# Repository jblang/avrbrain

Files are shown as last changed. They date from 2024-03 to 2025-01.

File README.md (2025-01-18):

# AVRBrain

AVRbrain is an [AVR128DB64](https://www.microchip.com/en-us/product/avr128db64) dev board.  The AVR Dx series are modern AVRs with many desireable features over the classic ATmega AVRs, such as multi-voltage I/O, configurable logic, advanced analog features, and a single-wire programming and debug interface.

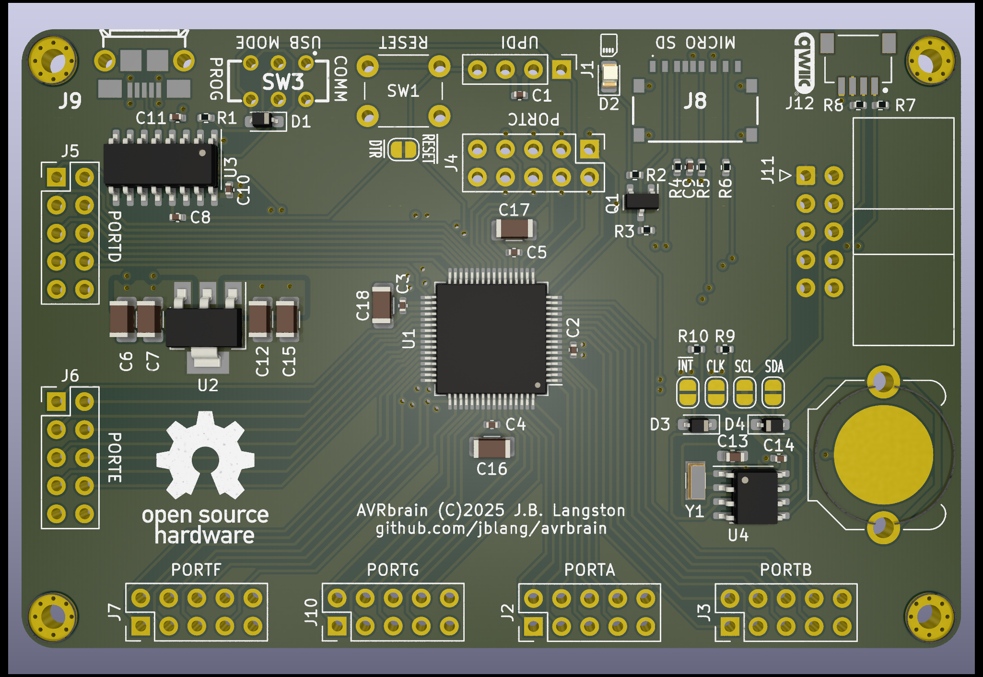
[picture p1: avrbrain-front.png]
3D Render


## Arduino Compatibility

AVRbrain is compatible with the [DxCore](https://github.com/SpenceKonde/DxCore) Arduino Core. I have tested the AVR128DB28 on a breadboard with the same programming circuit I intend to use on the finished board, and confirmed that it works.

Once flashed in UPDI programming mode, the Optiboot_Dx bootloader can be used to reprogram the board in serial comms mode, and there is an auto-reset circuit connected to the DTR line (possible to disable with a jumper).

## PlatformIO Compatibility

AVRbrain is compatible with [PlatformIO](https://platformio.org/) using the [Atmel megaAVR platform](https://docs.platformio.org/en/latest/platforms/atmelmegaavr.html).  PlatformIO supports Arduino development using DxCore, or native development using [avr-libc](https://www.nongnu.org/avr-libc/).  

Here's the `platformio.ini` that I used to build a simple non-Arduino led blinking example for the AVR128DB64:
```
[env:AVR128DB28]
platform = atmelmegaavr
platform_packages = platformio/toolchain-atmelavr@^3.70300.220127
board = AVR128DB28
upload_speed = 115200
upload_flags = 
    --tool
    uart
    --device
    avr128db28
    --uart
    $UPLOAD_PORT
    --clk
    $UPLOAD_SPEED
upload_command = pymcuprog write --erase $UPLOAD_FLAGS --filename $SOURCE
```

The above example can be made to work with DxCore just by adding the line `framework = arduino` to this file.

## Hardware Features
- Onboard CH340C USB-to-serial converter with a micro-USB connector, and a switch to select between USB communication or programming via SerialUPDI.  
- Onboard 3.3V regulator for MVIO. The board is configured to have 3.3V on PORTC and 5V on the other ports.
- SD card holder connected to 3.3V SPI Bus, and an I2C RTC (PCF8563T) with battery backup via CR 1612 coin cell.
- [UEXT port](https://www.olimex.com/Products/Modules/) that exports 3.3V UART, I2C, and SPI buses.  Many peripheral modules are available from Olimex.
- [Qwiic I2C port](https://www.sparkfun.com/qwiic) to work with the Qwiic and Stemma QT ecosystems. Many peripheral modules are available from Sparkfun and Adafruit.
- Headers breaking out all pins of the 8-bit ports A-G, except pin 7 of port F which is UPDI. Pin sockets can be used for stackable shield-style add-on boards, or pin headers can be used to connect to breadboards or elsewhere using IDC cables.
- Port F is used for UPDI, Reset, the USB UART, SD card chip select (level shifted), and optionally the RTC's interrupt and 32 kHz clock signals.
- The RTC's interrupt and 32 kHz clock signals can be connected to port F by adding a solder bridge on the surface mount jumper. The RTC can be disconnected from the I2C bus by cutting the traces in the SDA and SCL jumper pads in case of a conflict with other RTC devices.
- UPDI header for use with a [PicKit](https://www.microchip.com/en-us/development-tool/pg164150) and [MPLAB X](https://www.microchip.com/en-us/tools-resources/develop/mplab-x-ide) for debugging.
- Same size as a Raspberry Pi Model B, though it is not mechanically or electrically compatible. The right-side mounting holes are on the corners instead of toward the middle of the board, and no attempt has been made to reproduce the GPIO header pinout used on the Pi.

## Relationship to z80ctrl NG

[z80ctrl NG](https://github.com/jblang/z80ctrl/tree/master/hardware/nextgen) is the next-generation z80ctrl board I am designing concurrently with AVRbrain.  It uses all the same hardware components, including the AVR128DB64, the USB chip, RTC, voltage regulator, sd card slot, etc.  The primary difference is the pinout. The z80ctrl NG is intended to interface with the [RCBus](https://smallcomputercentral.com/rcbus/) parallel bus used primarily by Z80-based retrocomputers, whereas AVRbrain is intended as a general-purpose dev board with stacking shield-style modules or IDC cables.  z80ctrl also includes a 512K SRAM chip with optional banking that can be initialized by the AVR and then used by the 8-bit processor that z80ctrl shares a bus with.

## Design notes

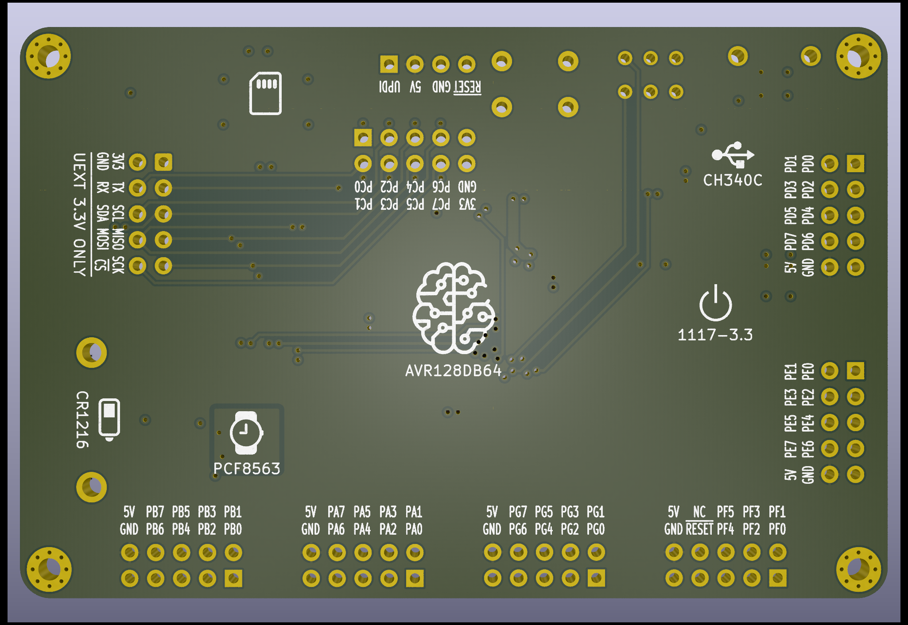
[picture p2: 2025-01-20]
avrbrain-back.png

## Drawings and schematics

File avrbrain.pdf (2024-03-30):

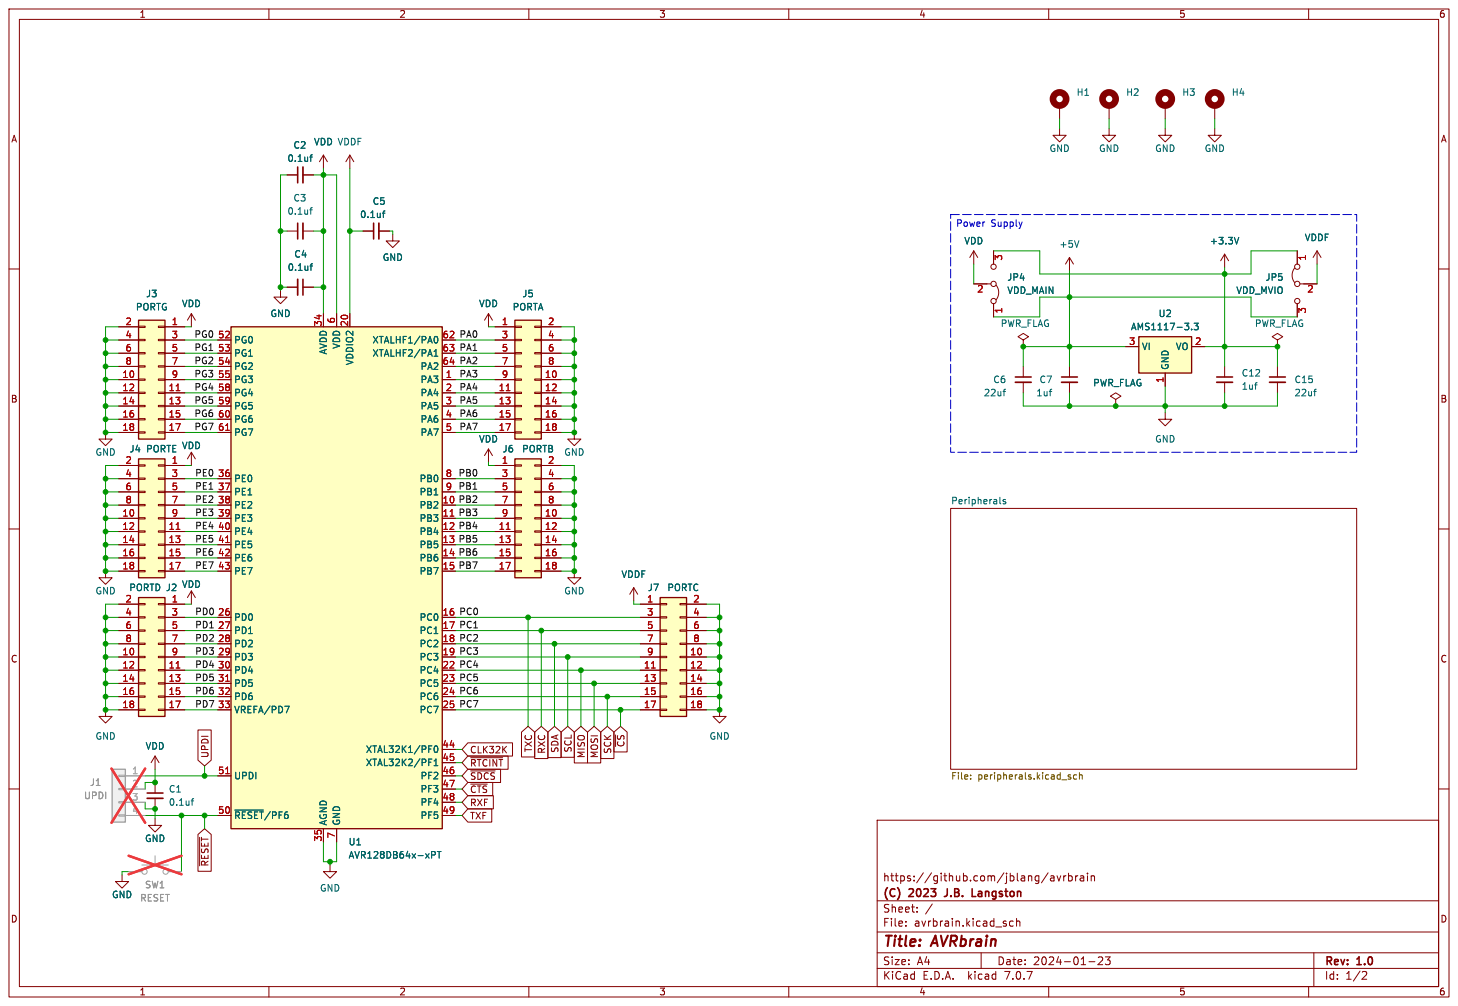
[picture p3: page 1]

https://github.com/jblang/avrbrain

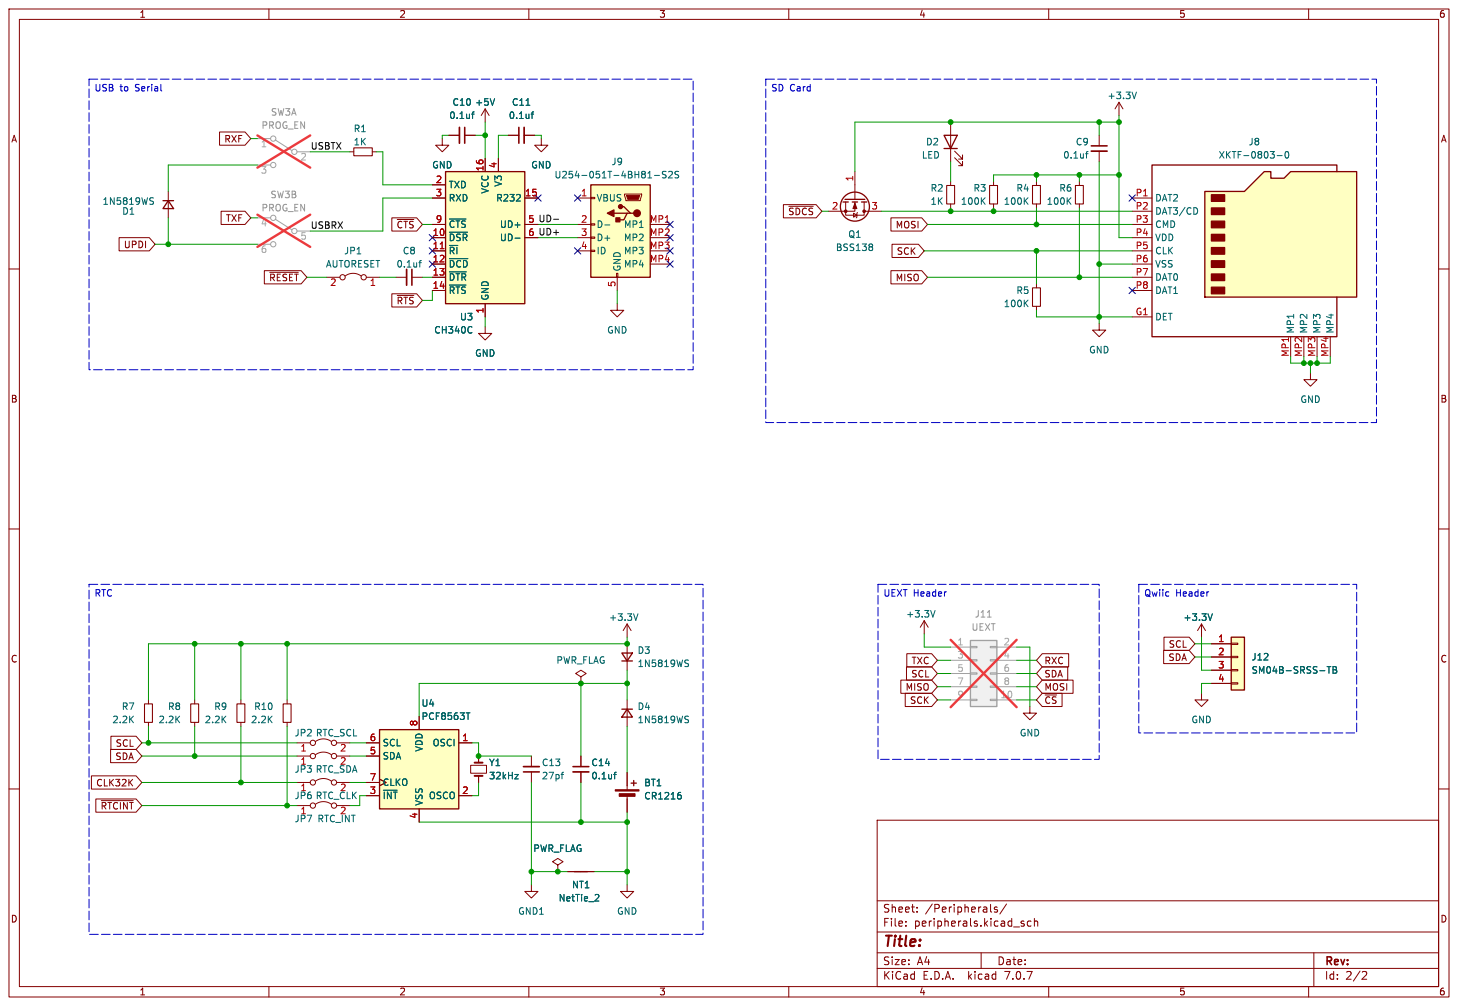
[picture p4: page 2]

USB to Serial RTC
JP1 AUTORESET R1

1 ~{DSR} 10 ~{RI} 11 ~{DCD} 12 ~{DTR} 13 ~{RTS} 14 R232 VCC 15 16 TXD 2 RXD 3 V3

4 UD+ 5 UD- 6 ~{CTS} 9 U3 CH340C GND

4 SDA 5 SCL 6 CLKO 7 VDD

Id: 2/2 Title: File: peripherals.kicad_sch Sheet: /Peripherals/

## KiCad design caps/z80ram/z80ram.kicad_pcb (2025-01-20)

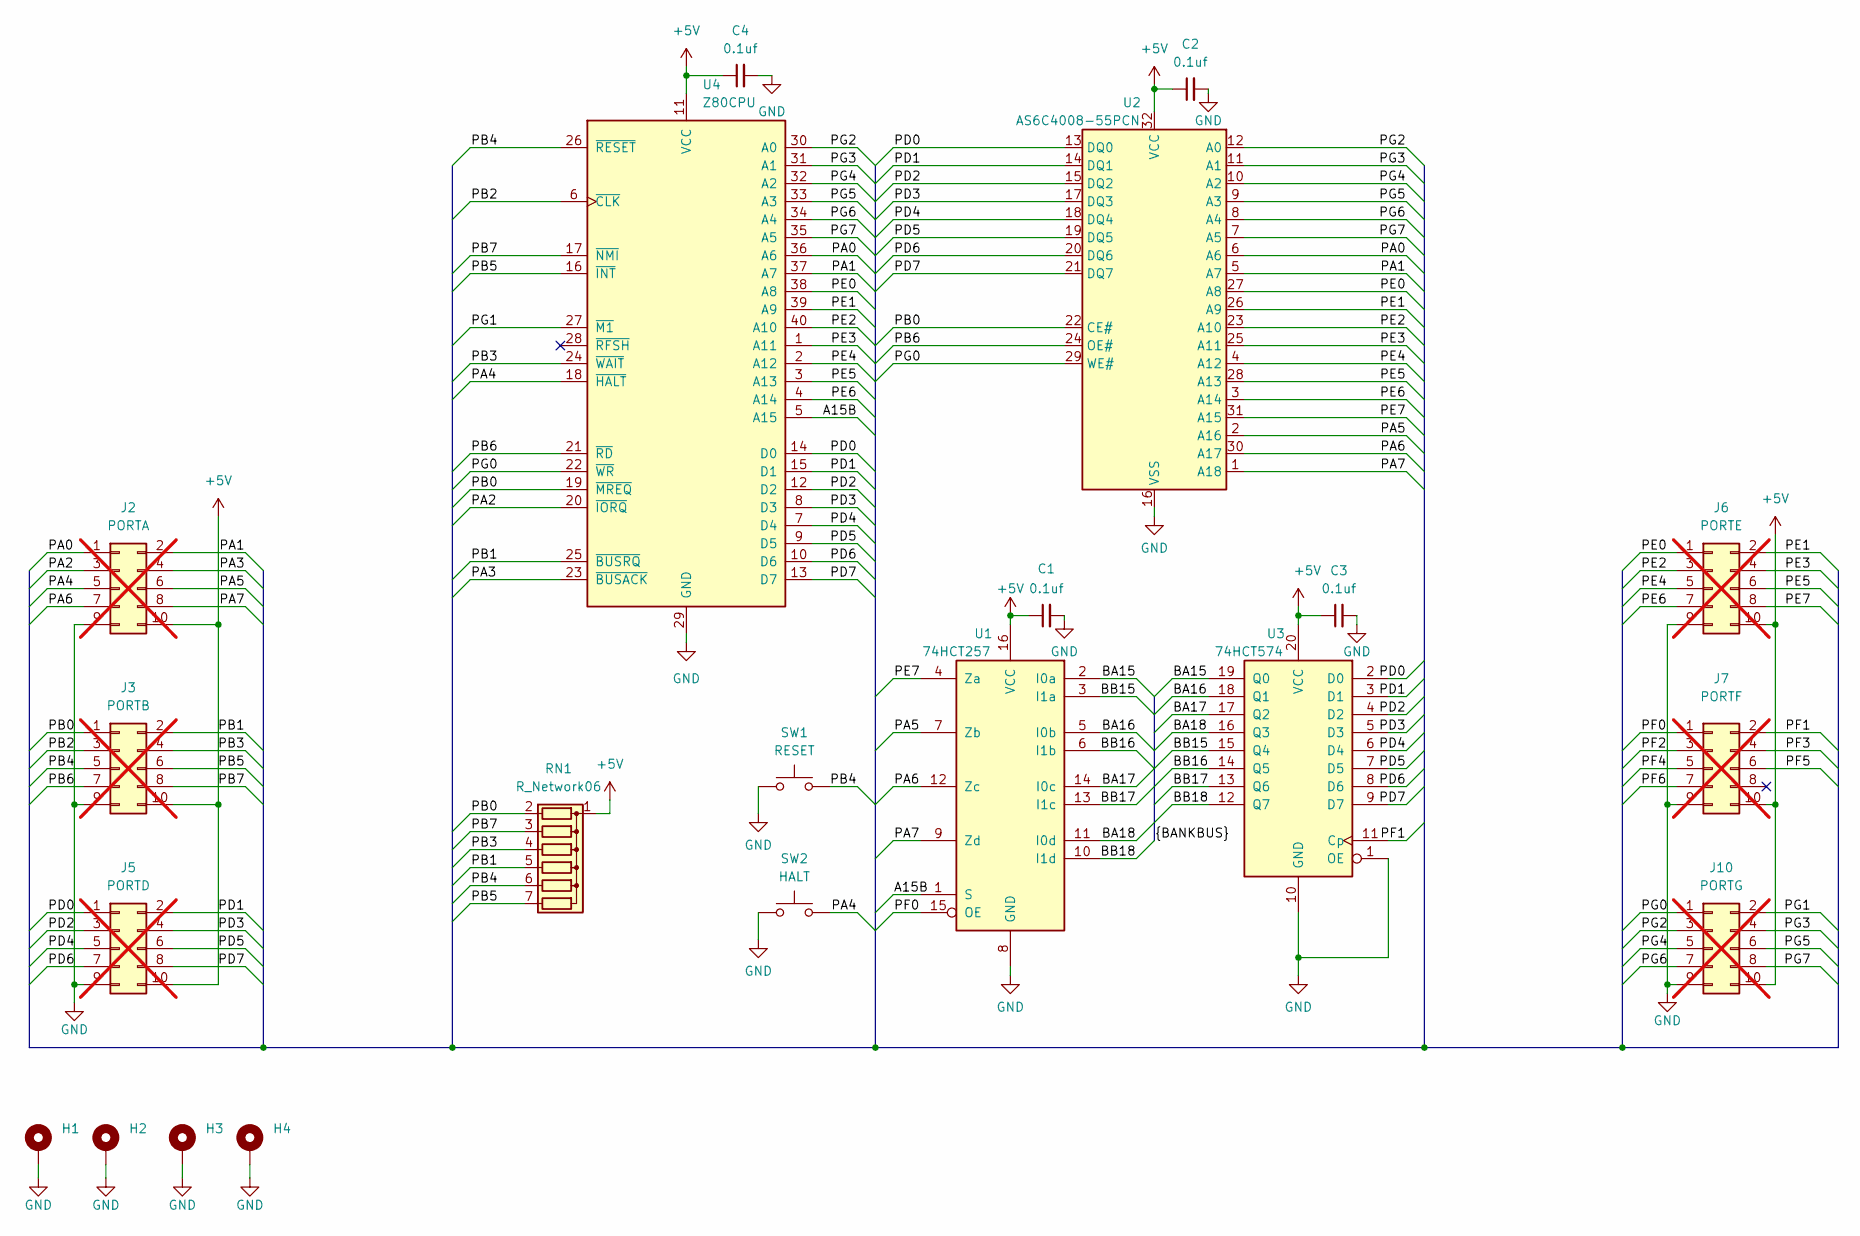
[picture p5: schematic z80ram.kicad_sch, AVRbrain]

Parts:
C1, C2, C3, C4: 0.1uf; C_Disc_D3.0mm_W1.6mm_P2.50mm
H1, H2, H3, H4: MountingHole_Pad; MountingHole_2.2mm_M2_Pad_Via
J2: PORTA; PinHeader_2x05_P2.54mm_Vertical; not fitted
J3: PORTB; PinHeader_2x05_P2.54mm_Vertical; not fitted
J5: PORTD; PinHeader_2x05_P2.54mm_Vertical; not fitted
J6: PORTE; PinHeader_2x05_P2.54mm_Vertical; not fitted
J7: PORTF; PinHeader_2x05_P2.54mm_Vertical; not fitted
J10: PORTG; PinHeader_2x05_P2.54mm_Vertical; not fitted
RN1: R_Network06; R_Array_SIP7
SW1: RESET; SW_PUSH_6mm
SW2: HALT; SW_PUSH_6mm
U1: 74HCT257; DIP-16_W7.62mm; MouserPN 595-SN74HCT257N; DigikeyPN 296-8406-5-ND
U2: AS6C4008-55PCN; DIP-32_W15.24mm; MouserPN 913-AS6C4008-55PCN; DigikeyPN 1450-1027-ND
U3: 74HCT574; DIP-20_W7.62mm; MouserPN 595-SN74HCT574N; DigikeyPN 296-1623-5-ND
U4: Z80CPU; DIP-40_W15.24mm

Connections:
+5V: C1.1, C2.1, C3.1, C4.1, J2.10, J3.10, J5.10, J6.10, J7.10, J10.10, RN1.1 (common), U1.16 (VCC), U2.32 (VCC), U3.20 (VCC), U4.11 (VCC)
/A15B: U1.1 (S), U4.5 (A15)
/BA15: U1.2 (I0a), U3.19 (Q0)
/BA16: U1.5 (I0b), U3.18 (Q1)
/BA17: U1.14 (I0c), U3.17 (Q2)
/BA18: U1.11 (I0d), U3.16 (Q3)
/BB15: U1.3 (I1a), U3.15 (Q4)
/BB16: U1.6 (I1b), U3.14 (Q5)
/BB17: U1.13 (I1c), U3.13 (Q6)
/BB18: U1.10 (I1d), U3.12 (Q7)
/PA0: J2.1, U2.6 (A6), U4.36 (A6)
/PA1: J2.2, U2.5 (A7), U4.37 (A7)
/PA2: J2.3, U4.20 (~IORQ)
/PA3: J2.4, U4.23 (~BUSACK)
/PA4: J2.5, SW2.2, U4.18 (~HALT)
/PA5: J2.6, U1.7 (Zb), U2.2 (A16)
/PA6: J2.7, U1.12 (Zc), U2.30 (A17)
/PA7: J2.8, U1.9 (Zd), U2.1 (A18)
/PB0: J3.1, RN1.2 (R1), U2.22 (CE#), U4.19 (~MREQ)
/PB1: J3.2, RN1.5 (R4), U4.25 (~BUSRQ)
/PB2: J3.3, U4.6 (~CLK)
/PB3: J3.4, RN1.4 (R3), U4.24 (~WAIT)
/PB4: J3.5, RN1.6 (R5), SW1.2, U4.26 (~RESET)
/PB5: J3.6, RN1.7 (R6), U4.16 (~INT)
/PB6: J3.7, U2.24 (OE#), U4.21 (~RD)
/PB7: J3.8, RN1.3 (R2), U4.17 (~NMI)
/PD0: J5.1, U2.13 (DQ0), U3.2 (D0), U4.14 (D0)
/PD1: J5.2, U2.14 (DQ1), U3.3 (D1), U4.15 (D1)
/PD2: J5.3, U2.15 (DQ2), U3.4 (D2), U4.12 (D2)
/PD3: J5.4, U2.17 (DQ3), U3.5 (D3), U4.8 (D3)
/PD4: J5.5, U2.18 (DQ4), U3.6 (D4), U4.7 (D4)
/PD5: J5.6, U2.19 (DQ5), U3.7 (D5), U4.9 (D5)
/PD6: J5.7, U2.20 (DQ6), U3.8 (D6), U4.10 (D6)
/PD7: J5.8, U2.21 (DQ7), U3.9 (D7), U4.13 (D7)
/PE0: J6.1, U2.27 (A8), U4.38 (A8)
/PE1: J6.2, U2.26 (A9), U4.39 (A9)
/PE2: J6.3, U2.23 (A10), U4.40 (A10)
/PE3: J6.4, U2.25 (A11), U4.1 (A11)
/PE4: J6.5, U2.4 (A12), U4.2 (A12)
/PE5: J6.6, U2.28 (A13), U4.3 (A13)
/PE6: J6.7, U2.3 (A14), U4.4 (A14)
/PE7: J6.8, U1.4 (Za), U2.31 (A15)
/PF0: J7.1, U1.15 (OE)
/PF1: J7.2, U3.11 (Cp)
/PF2: J7.3
/PF3: J7.4
/PF4: J7.5
/PF5: J7.6
/PF6: J7.7
/PG0: J10.1, U2.29 (WE#), U4.22 (~WR)
/PG1: J10.2, U4.27 (~M1)
/PG2: J10.3, U2.12 (A0), U4.30 (A0)
/PG3: J10.4, U2.11 (A1), U4.31 (A1)
/PG4: J10.5, U2.10 (A2), U4.32 (A2)
/PG5: J10.6, U2.9 (A3), U4.33 (A3)
/PG6: J10.7, U2.8 (A4), U4.34 (A4)
/PG7: J10.8, U2.7 (A5), U4.35 (A5)
GND: C1.2, C2.2, C3.2, C4.2, H1.1, H2.1, H3.1, H4.1, J2.9, J3.9, J5.9, J6.9, J7.9, J10.9, SW1.1, SW2.1, U1.8 (GND), U2.16 (VSS), U3.1 (OE), U3.10 (GND), U4.29 (GND)

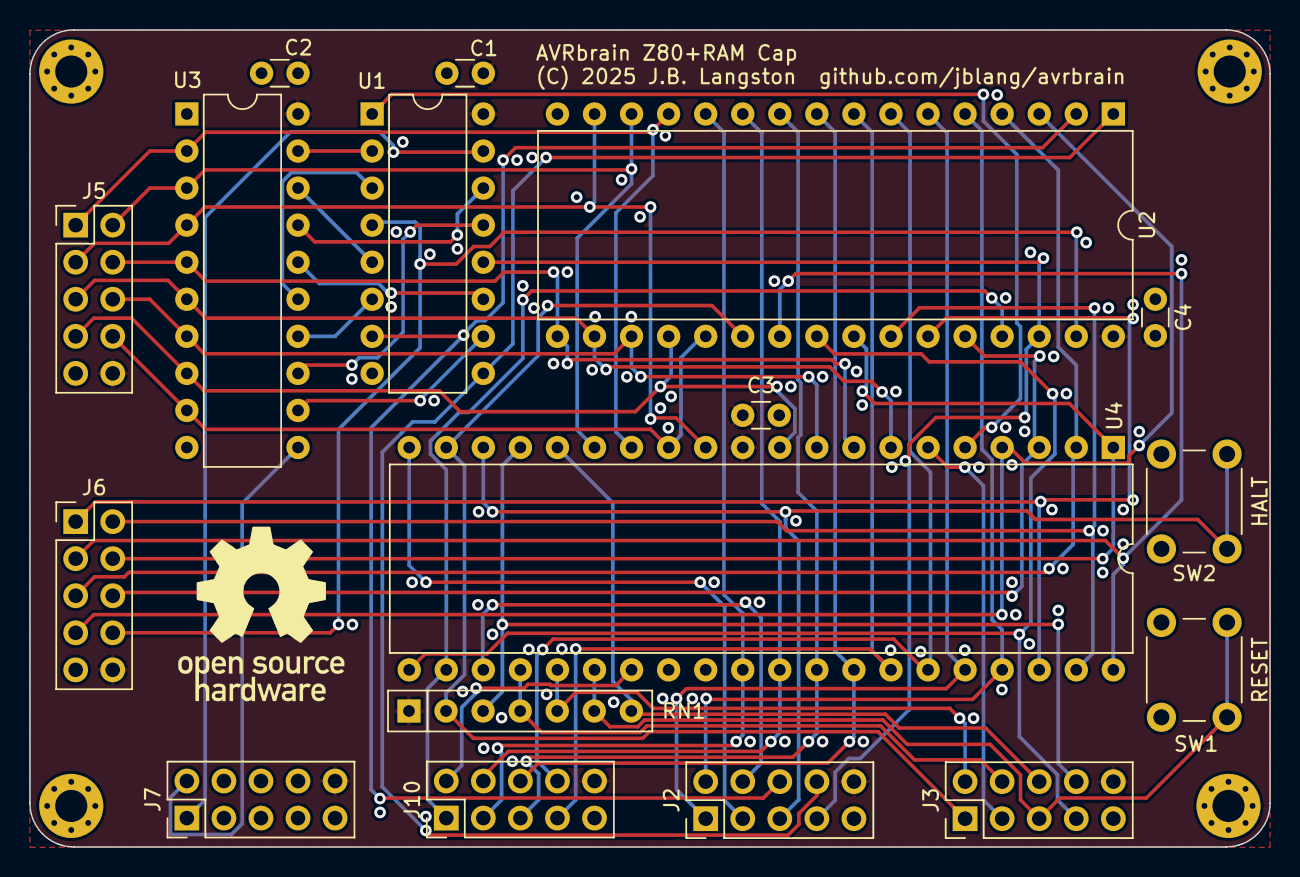
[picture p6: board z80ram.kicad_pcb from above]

Board: 4 copper layers, 85.0 x 56.0 mm, 21 parts (0 on the bottom side), 53 nets.

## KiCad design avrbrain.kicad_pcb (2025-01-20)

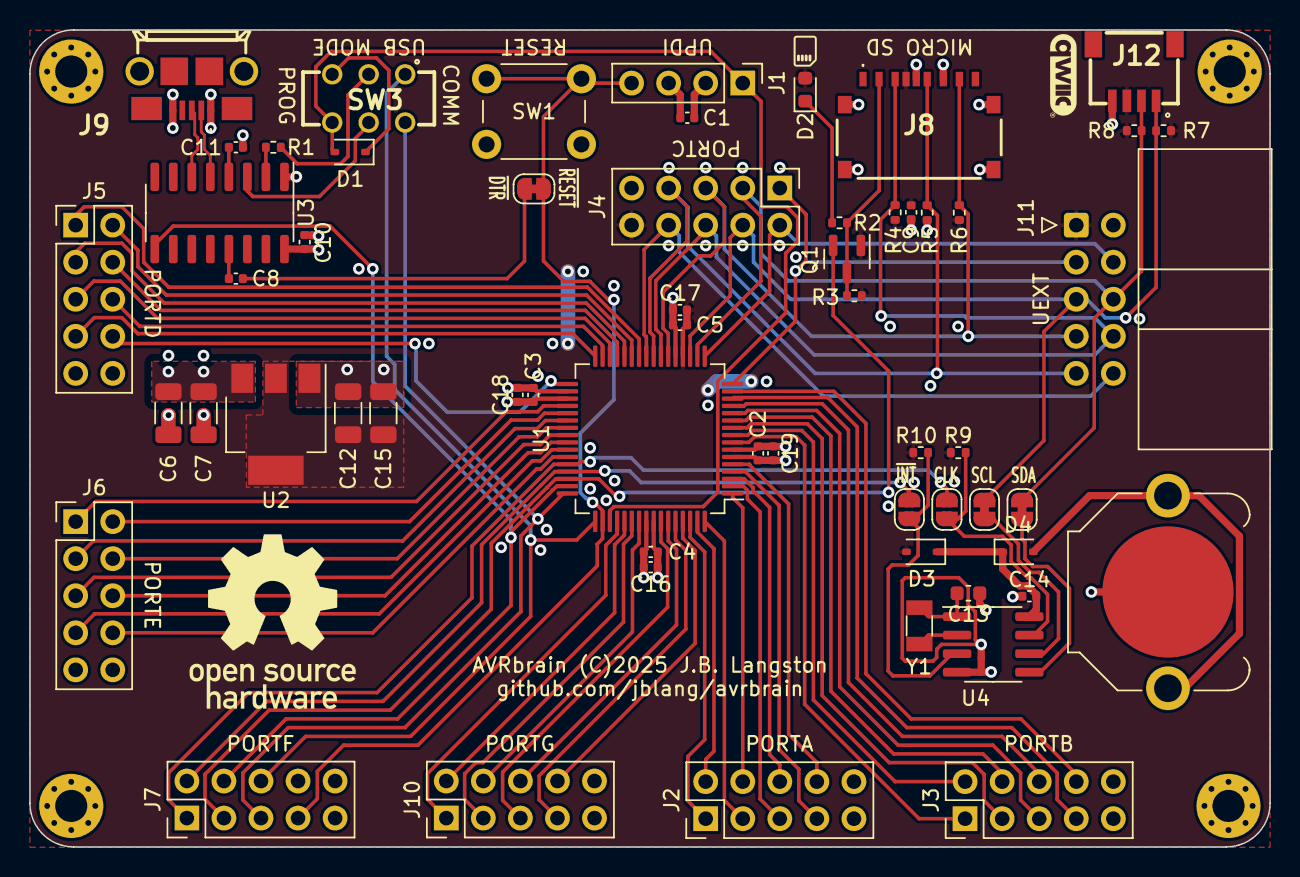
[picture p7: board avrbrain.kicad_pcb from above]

Board: 4 copper layers, 85.0 x 56.0 mm, 64 parts (0 on the bottom side), 79 nets.

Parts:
BT1: CR1216; BatteryHolder_Keystone_3001_1x12mm
C1, C2, C3, C4, C5, C8, C9, C10, C11, C14: 0.1uf; C_0402_1005Metric
C6, C15: 22uf; C_1206_3216Metric
C7, C12: 1uf; C_1206_3216Metric
C13: 27pf; C_0603_1608Metric
C16, C17, C18, C19: 1uf; C_0402_1005Metric
D1, D3, D4: 1N5819WS; D_SOD-323
D2: LED; LED_0603_1608Metric
H1, H2, H3, H4: MountingHole_Pad; MountingHole_2.2mm_M2_Pad_Via
J1: UPDI; PinHeader_1x04_P2.54mm_Vertical
J2: PORTA; PinHeader_2x05_P2.54mm_Vertical
J3: PORTB; PinHeader_2x05_P2.54mm_Vertical
J4: PORTC; PinHeader_2x05_P2.54mm_Vertical
J5: PORTD; PinHeader_2x05_P2.54mm_Vertical
J6: PORTE; PinHeader_2x05_P2.54mm_Vertical
J7: PORTF; PinHeader_2x05_P2.54mm_Vertical
J8: XKTF-0803-0; XKTF08030
J9: U254-051T-4BH81-S2S; U254051T4BH81S2S
J10: PORTG; PinHeader_2x05_P2.54mm_Vertical
J11: UEXT; IDC-Header_2x05_P2.54mm_Horizontal
J12: SM04B-SRSS-TB; SM04B-SRSS-TB_LFSN_
JP1: AUTORESET; SolderJumper-2_P1.3mm_Bridged_RoundedPad1.0x1.5mm
JP2: RTC_SCL; SolderJumper-2_P1.3mm_Bridged_RoundedPad1.0x1.5mm
JP3: RTC_SDA; SolderJumper-2_P1.3mm_Bridged_RoundedPad1.0x1.5mm
JP6: RTC_CLK; SolderJumper-2_P1.3mm_Open_RoundedPad1.0x1.5mm
JP7: RTC_INT; SolderJumper-2_P1.3mm_Open_RoundedPad1.0x1.5mm
NT1: NetTie_2; NetTie-2_SMD_Pad0.5mm
Q1: BSS138; SOT-23
R1, R2: 1K; R_0402_1005Metric
R3, R4, R5, R6: 100K; R_0402_1005Metric
R7, R8, R9, R10: 2.2K; R_0402_1005Metric
SW1: RESET; SW_PUSH_6mm
SW3: PROG_EN; JS202011CQN
U1: AVR128DB64x-xPT; TQFP-64_10x10mm_P0.5mm
U2: AMS1117-3.3; SOT-223-3_TabPin2
U3: CH340C; SOIC-16_3.9x9.9mm_P1.27mm
U4: PCF8563T; SOIC-8_3.9x4.9mm_P1.27mm
Y1: 32kHz; Crystal_SMD_3215-2Pin_3.2x1.5mm

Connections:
+3.3V: C5.1, C9.1, C12.1, C15.1, C17.2, D2.2 (A), D3.2 (A), J4.10, J8.P4 (VDD), J11.1, J12.3, Q1.1 (G), R3.1, R4.1, R6.1, R7.1, R8.1, R9.1, R10.1, U1.20 (VDDIO2), U2.2 (VO)
+5V: C1.1, C2.2, C3.2, C4.1, C6.1, C7.1, C10.1, C16.2, C18.2, C19.2, J1.2, J2.10, J3.10, J5.10, J6.10, J7.10, J9.1 (VBUS), J10.10, U1.6 (VDD), U1.34 (AVDD), U1.56 (VDD), U2.3 (VI), U3.16 (VCC)
/PA0: J2.1, U1.62 (XTALHF1/PA0)
/PA1: J2.2, U1.63 (XTALHF2/PA1)
/PA2: J2.3, U1.64 (PA2)
/PA3: J2.4, U1.1 (PA3)
/PA4: J2.5, U1.2 (PA4)
/PA5: J2.6, U1.3 (PA5)
/PA6: J2.7, U1.4 (PA6)
/PA7: J2.8, U1.5 (PA7)
/PB0: J3.1, U1.8 (PB0)
/PB1: J3.2, U1.9 (PB1)
/PB2: J3.3, U1.10 (PB2)
/PB3: J3.4, U1.11 (PB3)
/PB4: J3.5, U1.12 (PB4)
/PB5: J3.6, U1.13 (PB5)
/PB6: J3.7, U1.14 (PB6)
/PB7: J3.8, U1.15 (PB7)
/PD0: J5.1, U1.26 (PD0)
/PD1: J5.2, U1.27 (PD1)
/PD2: J5.3, U1.28 (PD2)
/PD3: J5.4, U1.29 (PD3)
/PD4: J5.5, U1.30 (PD4)
/PD5: J5.6, U1.31 (PD5)
/PD6: J5.7, U1.32 (PD6)
/PD7: J5.8, U1.33 (VREFA/PD7)
/PE0: J6.1, U1.36 (PE0)
/PE1: J6.2, U1.37 (PE1)
/PE2: J6.3, U1.38 (PE2)
/PE3: J6.4, U1.39 (PE3)
/PE4: J6.5, U1.40 (PE4)
/PE5: J6.6, U1.41 (PE5)
/PE6: J6.7, U1.42 (PE6)
/PE7: J6.8, U1.43 (PE7)
/PG0: J10.1, U1.52 (PG0)
/PG1: J10.2, U1.53 (PG1)
/PG2: J10.3, U1.54 (PG2)
/PG3: J10.4, U1.55 (PG3)
/PG4: J10.5, U1.58 (PG4)
/PG5: J10.6, U1.59 (PG5)
/PG6: J10.7, U1.60 (PG6)
/PG7: J10.8, U1.61 (PG7)
/Peripherals/UD+: J9.3 (D+), U3.6 (UD-)
/Peripherals/UD-: J9.2 (D-), U3.5 (UD+)
/Peripherals/USBRX: SW3.5 (B), U3.3 (RXD)
/Peripherals/USBTX: R1.2, SW3.2 (B)
CLK32K: J7.1, JP6.1 (A), U1.44 (XTAL32K1/PF0)
GND: BT1.2 (-), C1.2, C2.1, C3.1, C4.2, C5.2, C6.2, C7.2, C9.2, C10.2, C11.2, C12.2, C14.2, C15.2, C16.1, C17.1, C18.1, C19.1, H1.1, H2.1, H3.1, H4.1, J1.3, J2.9, J3.9, J4.9, J5.9, J6.9, J7.9, J8.G1 (DET), J8.MP1, J8.MP2, J8.MP3, J8.MP4, J8.P6 (VSS), J9.5 (GND), J10.9, J11.2, J12.4, NT1.2, R5.1, SW1.1, U1.7 (GND), U1.21 (GND), U1.35 (AGND), U1.57 (GND), U2.1 (GND), U3.1 (GND), U4.4 (VSS)
GND1: C13.1, NT1.1
MISO: J4.5, J8.P7 (DAT0), J11.7, R6.2, U1.22 (PC4)
MOSI: J4.6, J8.P3 (CMD), J11.8, R4.2, U1.23 (PC5)
unnamed: BT1.1 (+), D4.2 (A)
unnamed: D1.1 (K), SW3.3 (C)
unnamed: D2.1 (K), R2.2
unnamed: C14.1, D3.1 (K), D4.1 (K), U4.8 (VDD)
unnamed: J8.P2 (DAT3/CD), Q1.3 (D), R2.1, R3.2
unnamed: C8.2, JP1.1 (A)
unnamed: JP2.2 (B), U4.6 (SCL)
unnamed: JP3.2 (B), U4.5 (SDA)
unnamed: JP6.2 (B), R9.2, U4.7 (CLKO)
unnamed: JP7.2 (B), R10.2, U4.3 (~INT)
unnamed: R1.1, U3.2 (TXD)
unnamed: C11.1, U3.4 (V3)
unnamed: C8.1, U3.13 (~DTR)
unnamed: C13.2, U4.1 (OSCI), Y1.2
unnamed: U4.2 (OSCO), Y1.1
RXC: J4.2, J11.4, U1.17 (PC1)
RXF: J7.6, SW3.1 (A), U1.49 (PF5)
SCK: J4.7, J8.P5 (CLK), J11.9, R5.2, U1.24 (PC6)
SCL: J4.4, J11.5, J12.1, JP2.1 (A), R7.2, U1.19 (PC3)
SDA: J4.3, J11.6, J12.2, JP3.1 (A), R8.2, U1.18 (PC2)
TXC: J4.1, J11.3, U1.16 (PC0)
TXF: J7.5, SW3.4 (A), U1.48 (PF4)
UPDI: D1.2 (A), J1.1, SW3.6 (C), U1.51 (UPDI)
~CS: J4.8, J11.10, U1.25 (PC7)
~CTS: J7.4, U1.47 (PF3), U3.9 (~CTS)
~RESET: J1.4, J7.7, JP1.2 (B), SW1.2, U1.50 (~RESET/PF6)
~RTCINT: J7.2, JP7.1 (A), U1.45 (XTAL32K2/PF1)
~SDCS: J7.3, Q1.2 (S), U1.46 (PF2)

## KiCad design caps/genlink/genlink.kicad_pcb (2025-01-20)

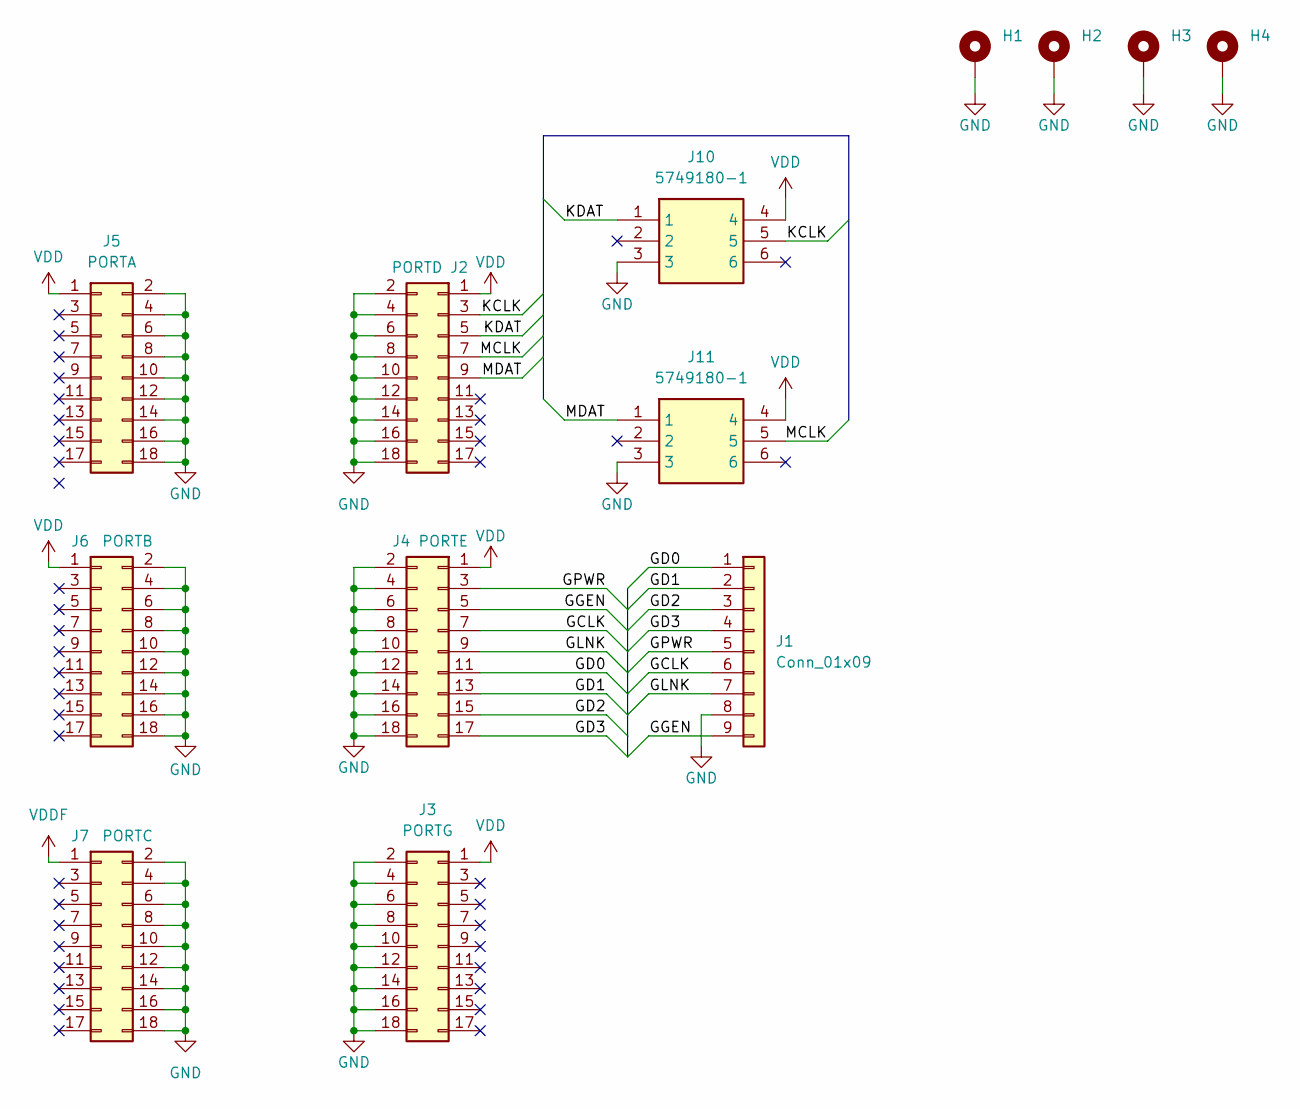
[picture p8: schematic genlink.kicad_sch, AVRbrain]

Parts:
H1, H2, H3, H4: MountingHole_Pad; MountingHole_2.2mm_M2_Pad_Via
J1: Conn_01x09; 182-009-213R561
J2: PORTD; PinSocket_2x09_P2.54mm_Vertical
J3: PORTG; PinSocket_2x09_P2.54mm_Vertical
J4: PORTE; PinSocket_2x09_P2.54mm_Vertical
J5: PORTA; PinSocket_2x09_P2.54mm_Vertical
J6: PORTB; PinSocket_2x09_P2.54mm_Vertical
J7: PORTC; PinSocket_2x09_P2.54mm_Vertical
J10, J11: 5749180-1; Mouser Part Number 571-5749180-1

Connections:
/GCLK: J1.6, J4.7
/GD0: J1.1, J4.11
/GD1: J1.2, J4.13
/GD2: J1.3, J4.15
/GD3: J1.4, J4.17
/GGEN: J1.9, J4.5
/GLNK: J1.7, J4.9
/GPWR: J1.5, J4.3
/KCLK: J2.3, J10.5
/KDAT: J2.5, J10.1
/MCLK: J2.7, J11.5
/MDAT: J2.9, J11.1
GND: H1.1, H2.1, H3.1, H4.1, J1.8, J2.2, J2.4, J2.6, J2.8, J2.10, J2.12, J2.14, J2.16, J2.18, J3.2, J3.4, J3.6, J3.8, J3.10, J3.12, J3.14, J3.16, J3.18, J4.2, J4.4, J4.6, J4.8, J4.10, J4.12, J4.14, J4.16, J4.18, J5.2, J5.4, J5.6, J5.8, J5.10, J5.12, J5.14, J5.16, J5.18, J6.2, J6.4, J6.6, J6.8, J6.10, J6.12, J6.14, J6.16, J6.18, J7.2, J7.4, J7.6, J7.8, J7.10, J7.12, J7.14, J7.16, J7.18, J10.3, J11.3
VDD: J2.1, J3.1, J4.1, J5.1, J6.1, J10.4, J11.4
VDDF: J7.1

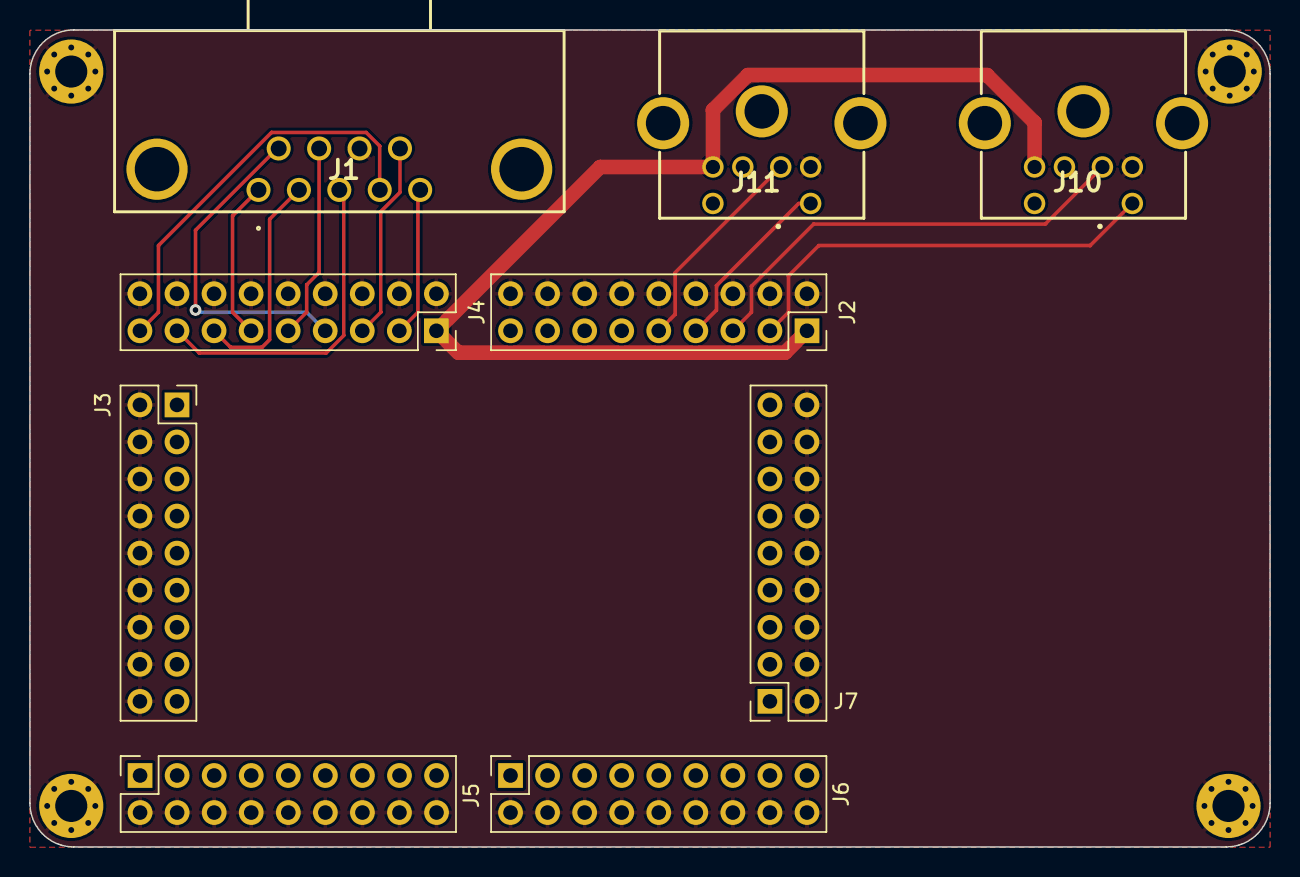
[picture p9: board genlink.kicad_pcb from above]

Board: 2 copper layers, 85.0 x 56.0 mm, 13 parts (0 on the bottom side), 14 nets.

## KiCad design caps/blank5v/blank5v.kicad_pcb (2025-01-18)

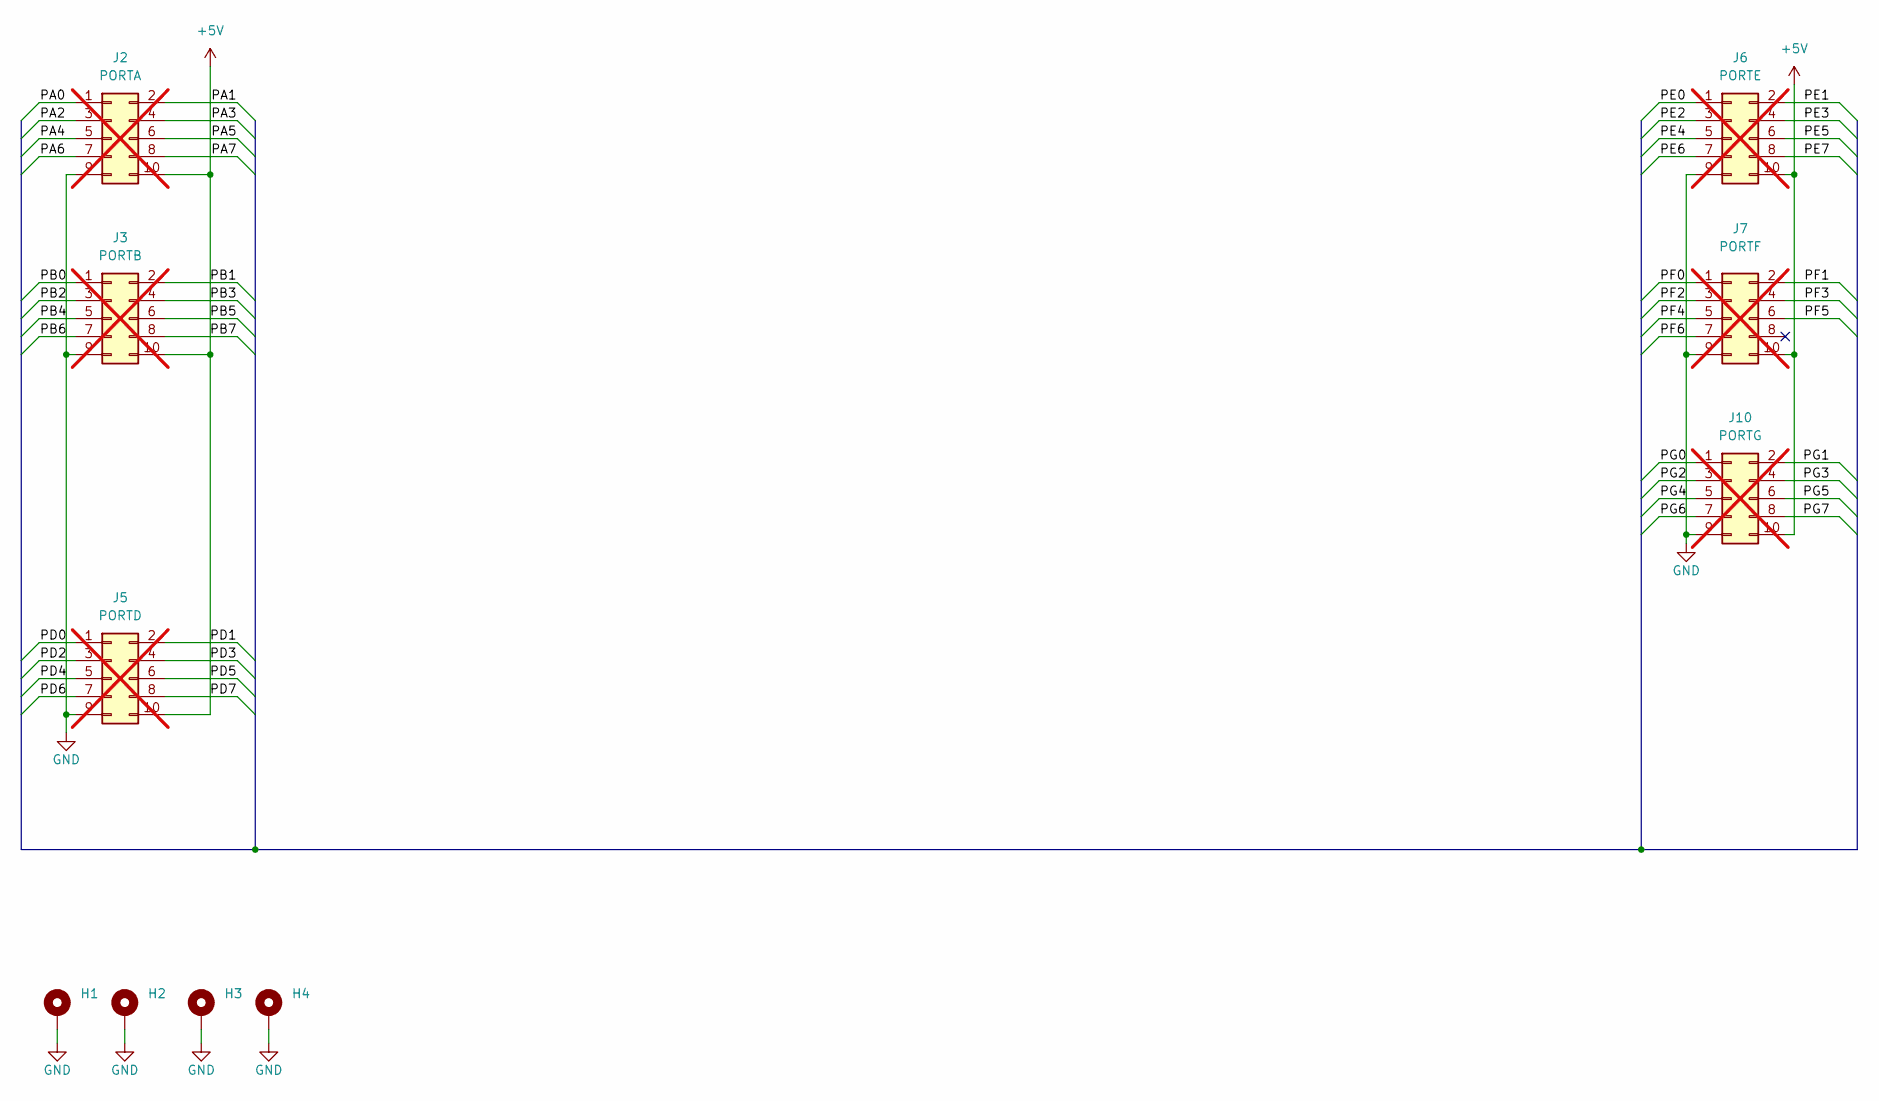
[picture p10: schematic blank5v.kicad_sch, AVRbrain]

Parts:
H1, H2, H3, H4: MountingHole_Pad; MountingHole_2.2mm_M2_Pad_Via
J2: PORTA; PinHeader_2x05_P2.54mm_Vertical; not fitted
J3: PORTB; PinHeader_2x05_P2.54mm_Vertical; not fitted
J5: PORTD; PinHeader_2x05_P2.54mm_Vertical; not fitted
J6: PORTE; PinHeader_2x05_P2.54mm_Vertical; not fitted
J7: PORTF; PinHeader_2x05_P2.54mm_Vertical; not fitted
J10: PORTG; PinHeader_2x05_P2.54mm_Vertical; not fitted

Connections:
+5V: J2.10, J3.10, J5.10, J6.10, J7.10, J10.10
/PA0: J2.1
/PA1: J2.2
/PA2: J2.3
/PA3: J2.4
/PA4: J2.5
/PA5: J2.6
/PA6: J2.7
/PA7: J2.8
/PB0: J3.1
/PB1: J3.2
/PB2: J3.3
/PB3: J3.4
/PB4: J3.5
/PB5: J3.6
/PB6: J3.7
/PB7: J3.8
/PD0: J5.1
/PD1: J5.2
/PD2: J5.3
/PD3: J5.4
/PD4: J5.5
/PD5: J5.6
/PD6: J5.7
/PD7: J5.8
/PE0: J6.1
/PE1: J6.2
/PE2: J6.3
/PE3: J6.4
/PE4: J6.5
/PE5: J6.6
/PE6: J6.7
/PE7: J6.8
/PF0: J7.1
/PF1: J7.2
/PF2: J7.3
/PF3: J7.4
/PF4: J7.5
/PF5: J7.6
/PF6: J7.7
/PG0: J10.1
/PG1: J10.2
/PG2: J10.3
/PG3: J10.4
/PG4: J10.5
/PG5: J10.6
/PG6: J10.7
/PG7: J10.8
GND: H1.1, H2.1, H3.1, H4.1, J2.9, J3.9, J5.9, J6.9, J7.9, J10.9

Board: 4 copper layers, 10 parts (0 on the bottom side), 2 nets, no tracks yet.

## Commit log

2024-01-10 Initial layout of new AVR128DB64 dev board
    [avrbrain.kicad_pcb, avrbrain.kicad_sch]
2024-01-15 Tweaks to layout, finish all connections
    [avrbrain.kicad_pcb, avrbrain.kicad_sch]
2024-01-24 Finish layout and routing
    [avrbrain.kicad_pcb, avrbrain.kicad_sch, peripherals.kicad_sch]
2024-01-25 Put resistor before switch to avoid parasitic powering of the board
    [avrbrain.kicad_pcb, peripherals.kicad_sch]
2024-03-30 Final touches
    [avrbrain.kicad_pcb, avrbrain.kicad_sch, peripherals.kicad_sch]
2025-01-18 Switch to 4 layer; reduce connector size and move to edge
    [avrbrain.kicad_pcb, avrbrain.kicad_sch, peripherals.kicad_sch]
2025-01-18 Add blank template with 5V connectors
    [blank5v.kicad_pcb, blank5v.kicad_sch]
2025-01-18 Add Z80+RAM cap
    [z80ram.kicad_pcb, z80ram.kicad_sch]
2025-01-20 OCD tweaks
    [z80ram.kicad_pcb]
2025-01-20 Add silkscreen pinouts
    [avrbrain.kicad_pcb]
2025-01-20 Final (?!) tweaks
    [avrbrain.kicad_pcb, avrbrain.kicad_sch, peripherals.kicad_sch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]
2025-01-20 Add reset and halt buttons to Z80 cap
    [z80ram.kicad_pcb, z80ram.kicad_sch]
2025-01-20 Add custom symbols and footprints
    [avrbrain.kicad_pcb, peripherals.kicad_sch]
2025-01-20 Add LCSC part numbers
    [avrbrain.kicad_pcb, avrbrain.kicad_sch, genlink.kicad_pcb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]
2025-01-20 Fix LCSC field name, gerber settings
    [avrbrain.kicad_pcb, avrbrain.kicad_sch, peripherals.kicad_sch]
2025-01-20 Final tweaks after uploading to JLC
    [avrbrain.kicad_pcb, avrbrain.kicad_sch, peripherals.kicad_sch]
2025-01-20 Generate gerbers for Z80+RAM cap
    [z80ram.kicad_pcb]

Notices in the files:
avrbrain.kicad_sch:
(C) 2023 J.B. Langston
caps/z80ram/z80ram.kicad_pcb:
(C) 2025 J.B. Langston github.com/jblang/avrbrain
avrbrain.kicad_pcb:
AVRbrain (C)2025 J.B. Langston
